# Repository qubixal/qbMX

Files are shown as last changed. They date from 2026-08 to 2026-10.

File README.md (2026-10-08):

# qbMX

> A custom mechanical keyboard built from scratch for [Hack Club Keeb](https://keeb.hackclub.com/) YSWS.

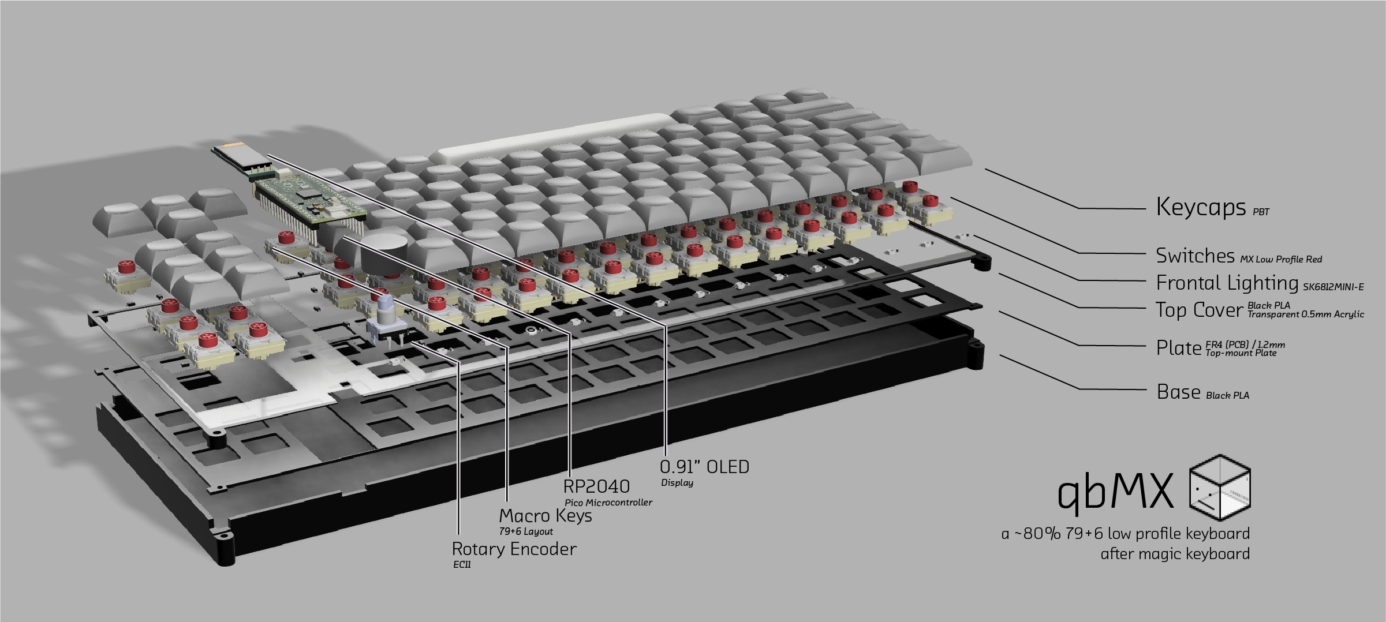
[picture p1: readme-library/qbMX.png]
Full Render


## Overview

**qbMX** is a fully custom mechanical keyboard designed in KiCad and Fusion. It features:

- **85-key (79+6) layout** with a rotary encoder, modelled after Apple's Magic Keyboard.
- **Cherry MX Low-Profile Red** switches, and on-plate stabalisers (instead of on-pcb)
- Uses the **RP2040 microcontroller** (Orpheus Pico)
- A 0.91" **128x32 OLED display**
- 15 mini-LEDs at the top of the keyboard
- Custom PCB, ordered and assembled by me

## Why I Built qbMX

I wanted to learn about and build a keyboard myself, since I'd never done it before.
Designing the matrix and optimising GPIO lanes with functionality was a cool challenge. Oh, and I just wanted a keyboard; and Keeb gave me an excuse to make it.

## What's in This Repo

| Path | Description |
| --- | --- |
| `keeb.kicad_sch` | Schematic |
| `keeb.kicad_pcb` / `keeb.kicad_pro` | KiCad PCB layout & project |
| `pcb/` + `pcb.zip` | Gerbers & drill files (F.Cu, B.Cu, silkscreen, mask, Edge.Cuts) |
| `*.step` | 3D models (board, OLED, rotary encoder, plate) |
| `key-switches.pretty/`, `extra_key.pretty/` | Footprint libraries |
| `readme-library/` | Photos & renders |
| `bom.csv` | Bill of materials |

## Use Guide

After building all physical hardware, download the firmware folder then:

```cmd
export PICO_SDK_PATH=/path/to/pico-sdk

cd firmware && mkdir build && cd build

cmake .. && make
```

hold BOOTSEL on the Pico, plug in the USB and drag qbmx.uf2 to the mass storage device.

OLED Shows 5 pages:
0. Current keyboard layer
1. Custom text/bitmap
2. LED mode + brightness
3. WPM counter with bar graph
4. Host temps (CPU avg, GPU avg, Pico internal temp)

For temperature tracking to work properly,
1. Install pyserial
```cmd
pip3 install pyserial
```
2. Run host script which auto-detects the Pico port
```cmd
python3 firmware/host_temp.py
```

> **Note:** osx-cpu-temp will return 0.0°C on Apple Silicon Macs without SMC entitlements; where the OLED will show N/A in this case. You may instead compile `osx-cpu-temp` from source or use  `sudo powermetrics`.

### Programmable Keys (Column 14, Rows 0-5)
By default they are mapped to F13-F18 (USB HID keycodes 0x68 -> 0x6D), which is recognised by every major OS. It can be remapped in system settings.

Other functions include:
Short press rotary encoder to pause, Long press rotary encoder to toggle between volume and brightness (backlight) mode

## Build Log / Journal

See [`JOURNAL.md`](JOURNAL.md).

## BOM

See [`bom.csv`](bom.csv).

## Acknowledgements

- [Hack Club Keeb](https://keeb.hackclub.com/) for the program
- siderakb/key-switches.pretty and eblaster/marbastlib libraries
- GrabCAD models [switch](https://grabcad.com/library/low-profile-cherry-mx-red-1), [encoder](https://grabcad.com/library/11mm-metal-shaft-rotary-encoders-tht-vertical-w-push-on-switch-1), [OLED](https://grabcad.com/library/0-91-128x32-oled-display-1)
- Github models [keycaps](https://github.com/anhthang/dsa-keycap/)

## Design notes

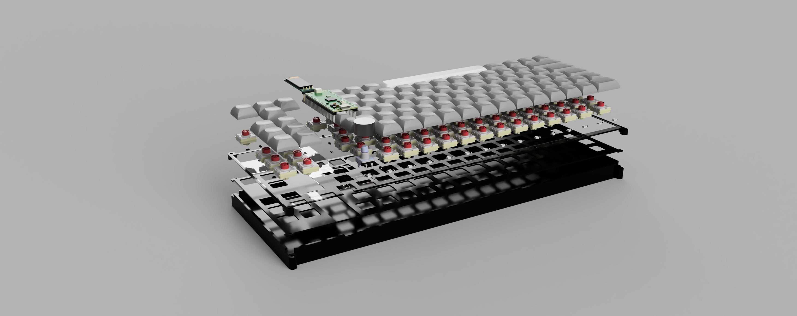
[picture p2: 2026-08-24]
render.PNG

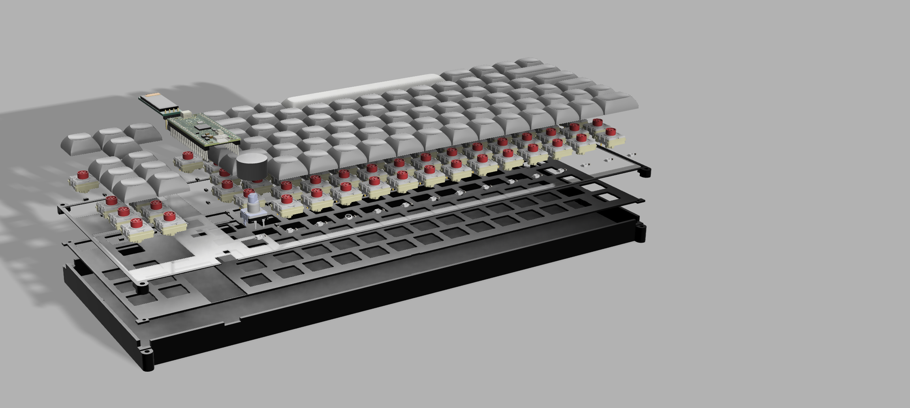
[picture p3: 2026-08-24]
render_clean.png

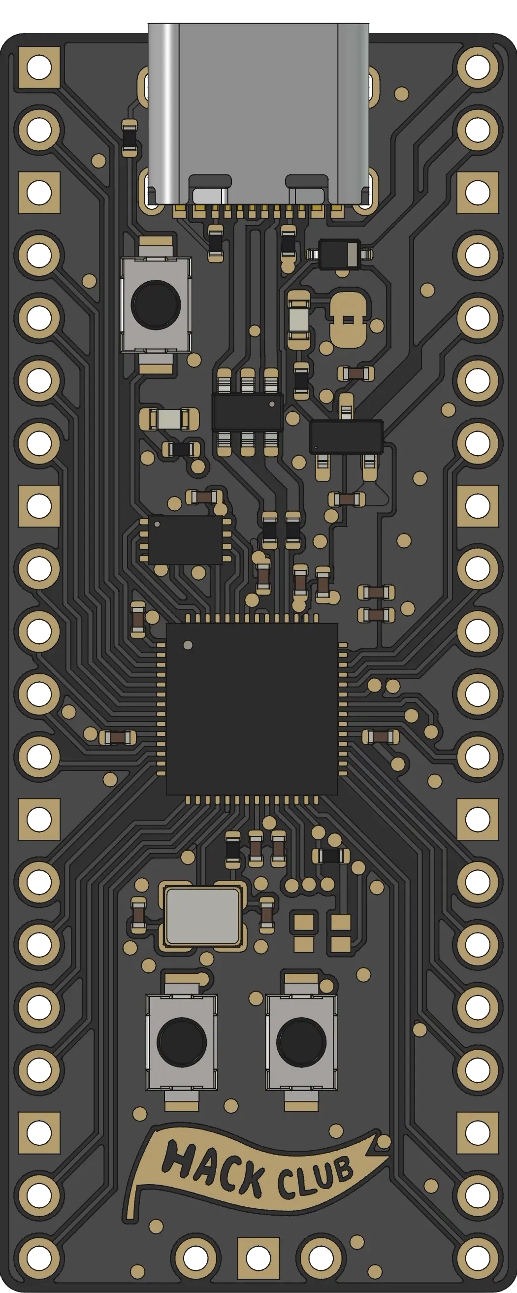
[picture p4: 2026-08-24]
orph-pico.png

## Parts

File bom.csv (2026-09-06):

Designator | Item | Item No/LCSC | Supplier | Variant | Qty | Unit $AUD | Total $AUD | Link
1 | Orpheus Pico |  | Hack Club |  | 1 | ? | ?
2 | Cherry MX Low Profile Red | CHERRY__________________MX Low Profile RGB | Taobao | 100 pack | 1 | 46.04 | 46.04 | https://item.taobao.com/item.htm?id=673935710462
3 | Plate Mount Stab | __Chosfox MX________ ______________ | Taobao | 6.25u*1+2u*2 | 1 | 5.6 | 5.6 | https://item.taobao.com/item.htm?id=921829717536
4 | M3*10 Screw | M2.5M3M4M5M6M8__304___________________ | Taobao | 50 pack | 1 | 1.45 | 1.45 | https://detail.tmall.com/item.htm?id=650868762254
5 | M2*3 Screw | M2_______CM__3.3_0.3_______*2/2.5/3/4/5/10 | Taobao | 100 pack | 1 | 0.62 | 0.62 | https://detail.tmall.com/item.htm?id=610559538489
6 | EC11 Rotary Encoder | EC11________10/15/20/25mm__ ___________ | Taobao | __10mm | 1 | 1.54 | 1.54 | https://item.taobao.com/item.htm?id=586360534043
7 | 1N4148W Diode | C84367 | LCSC |  | 100 | 0.01 | 1 | https://www.lcsc.com/product-detail/C84367.html
8 | 0.91" OLED Screen | 0.91_OLED_____128_32___4_iic__SSD1306 | Taobao | 4PIN 0.91_ _______ | 1 | 1.8 | 1.8 | https://item.taobao.com/item.htm?id=824313570601
9 | 0.1uF 0603 Cap | C14663 | LCSC |  | 50 | 0.02 | 1 | https://www.lcsc.com/product-detail/C14663.html
10 | OPSCO Optoelectronics SK6812MINI-E | C5149201 | LCSC |  | 15 | 0.11 | 1.65 | https://www.lcsc.com/product-detail/C5149201.html
11 | PCB - Keyboard |  | JLCPCB |  | 1 | 32.99 | 32.99
12 | PCB - Plate (FR4) |  | JLCPCB | 1.2mm | 1 | 34.95 | 34.95
13 | PCB Shipping |  | JLCPCB | - | 1 | 21.71 | 21.71
14 | Case (3D print + Acrylic) | - | - | - | - | - | -
15 | Silicone Padding | ______________________________ | Taobao | 15 pack 30*9*1mm | 1 | 1.03 | 1.03
16 | PBT Keycaps | ______ABS\PBT____68\84\98\104\87\100\108__ | Taobao | PBT White Set | 1 | 19.82 | 19.82
17 | Taobao Shipping |  | Taobao | Combined + GST | 1 | 18.61 | 18.61
 |  |  |  |  |  | TOTAL | 189.81
 |  |  |  |  |  | TOTAL (USD) | 136.6632

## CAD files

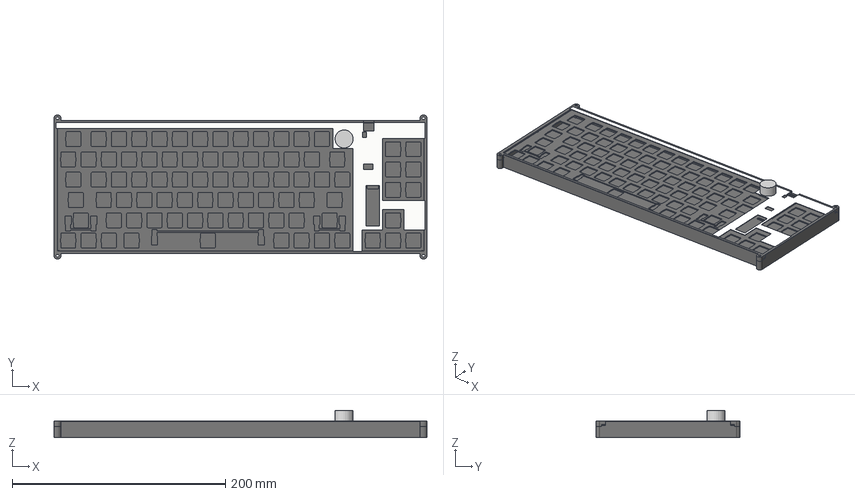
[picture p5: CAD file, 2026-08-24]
case-assembly.step
350.0 x 135.5 x 25.6 mm

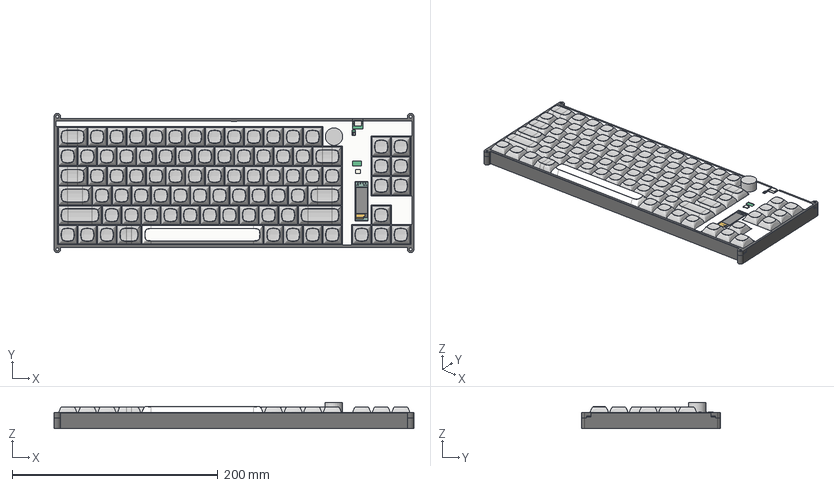
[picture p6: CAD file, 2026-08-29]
prod-3d-models/qbMX-assembly.step
350.0 x 135.5 x 25.6 mm

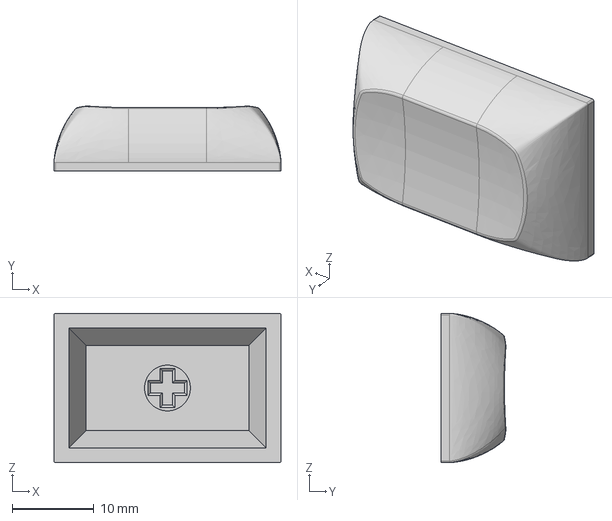
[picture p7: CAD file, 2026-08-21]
dsa-keycap-master/DSA 1.5u.step
27.7 x 7.91 x 18.2 mm

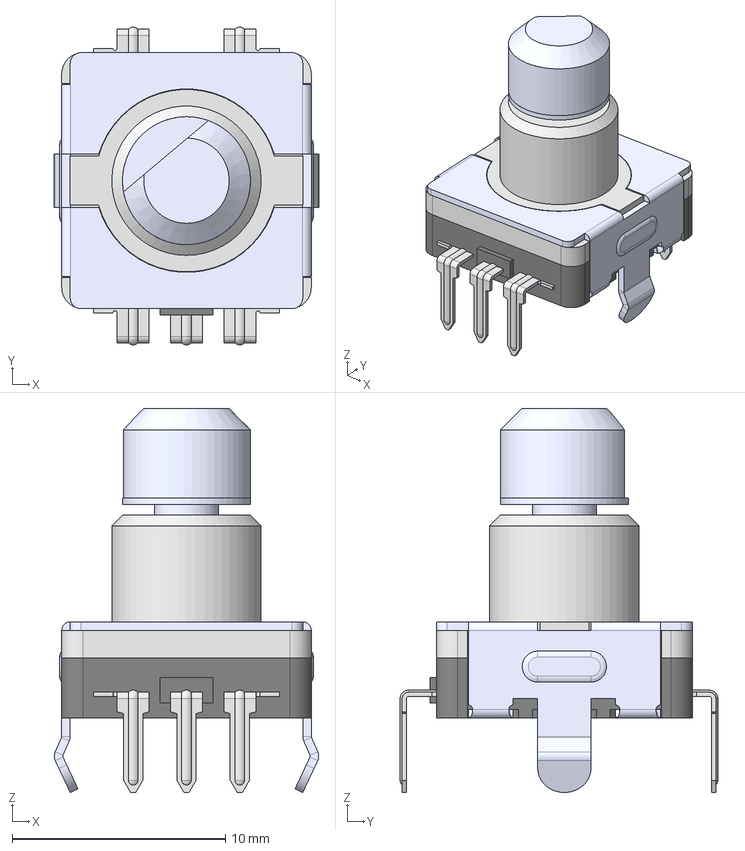
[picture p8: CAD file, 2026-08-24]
EC11-THT-10F-black.step
12.4 x 14.9 x 18.0 mm

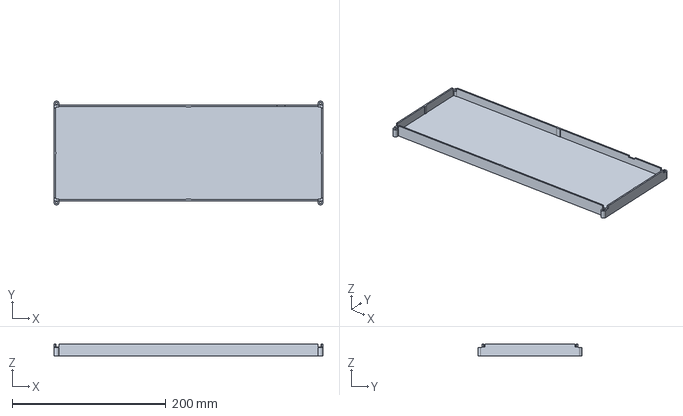
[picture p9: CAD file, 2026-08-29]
prod-3d-models/base.step
350.0 x 135.5 x 15.0 mm

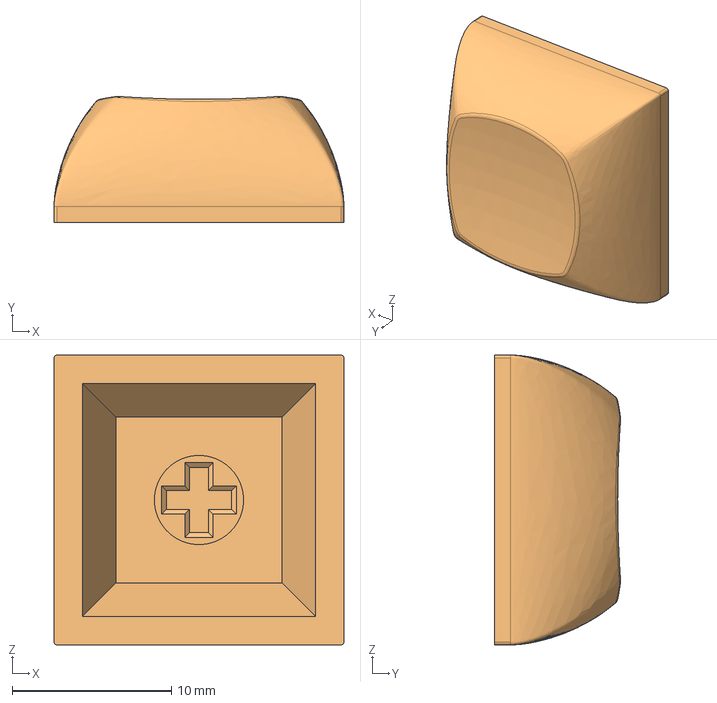
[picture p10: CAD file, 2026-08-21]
dsa-keycap-master/DSA 1u.step
18.2 x 7.91 x 18.2 mm

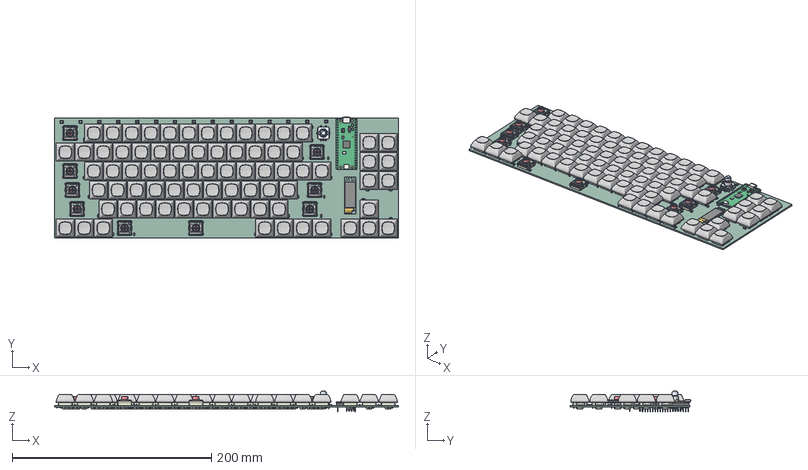
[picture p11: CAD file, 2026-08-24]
pcb.step
345.0 x 121.0 x 20.8 mm
Stem x 85
Top Case x 85
Bottom Case x 85
Spring x 85
MX Mount v1 x 76
D_SOD-123 x 86
128x32-OLED v4
RaspberryPi_Pico_H_Module_KiCad
RaspberryPi_Pico_Header_DIP-40_H2.54mm_KiCad
EC11-Base
EC11-Shaft-F
EC11-Housing-THT
C_0603_1608Metric x 15
Pin1 x 15
Pin2 x 15
Pin3 x 15
Pin4 x 15
keeb_PCB

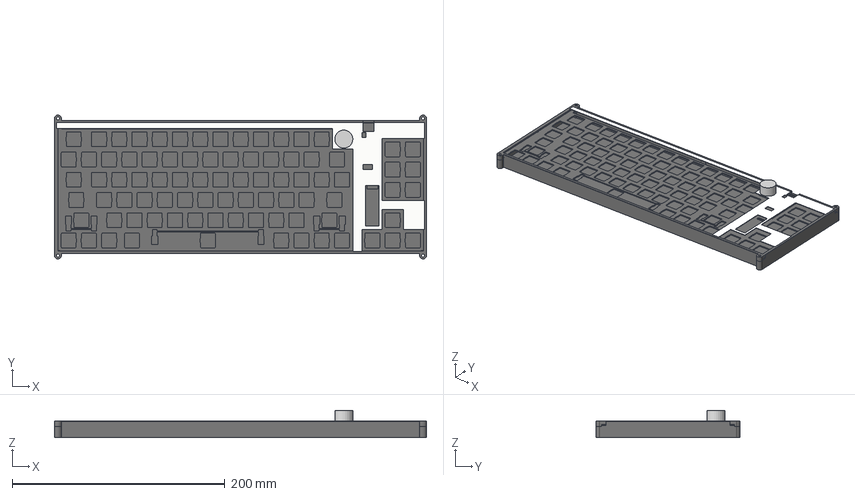
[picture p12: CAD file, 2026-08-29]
prod-3d-models/case.step
350.0 x 135.5 x 25.6 mm

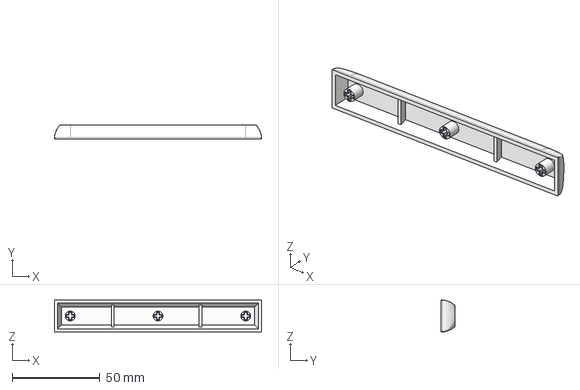
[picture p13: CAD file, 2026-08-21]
dsa-keycap-master/DSA Spacebar 6.25u (50mm spacing).step
118.0 x 8.00 x 18.2 mm

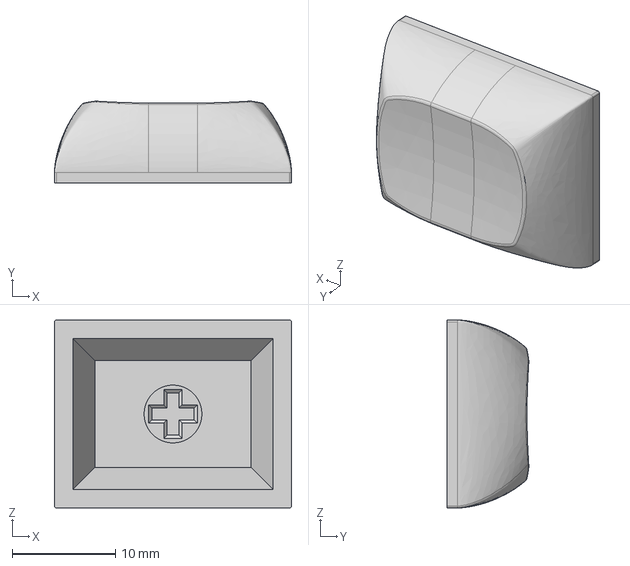
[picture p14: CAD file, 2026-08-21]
dsa-keycap-master/DSA 1.25u.step
22.9 x 7.91 x 18.2 mm

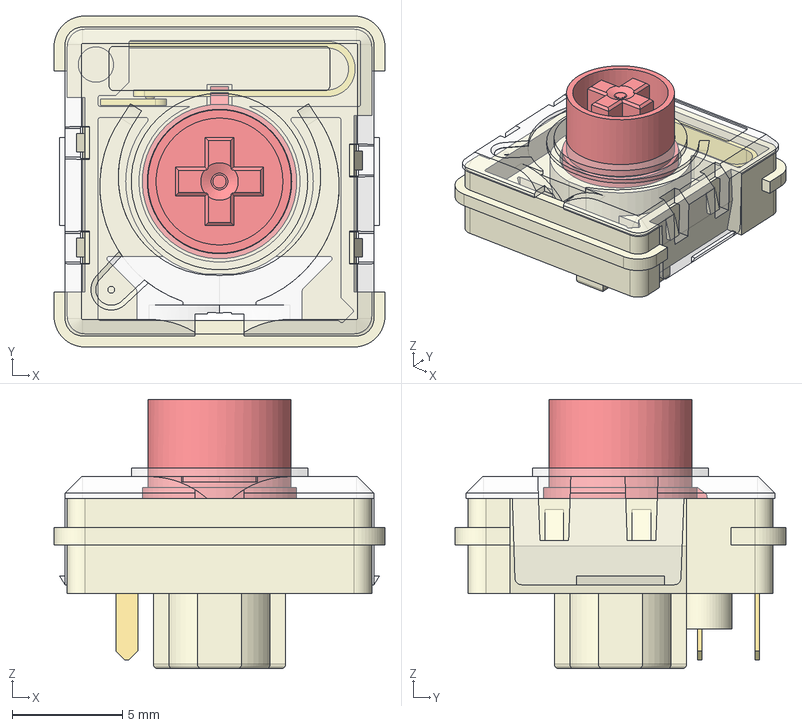
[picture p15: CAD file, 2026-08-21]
lpred.step
15.0 x 15.0 x 12.2 mm
Stem
Top Case
Bottom Case
Spring

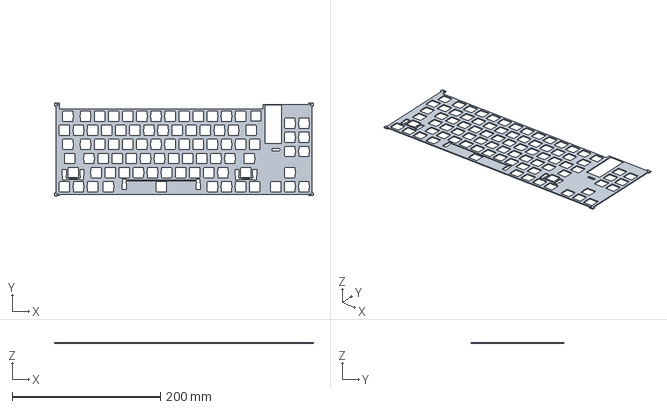
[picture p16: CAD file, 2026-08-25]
prod-3d-models/plate.step
350.0 x 125.0 x 1.20 mm

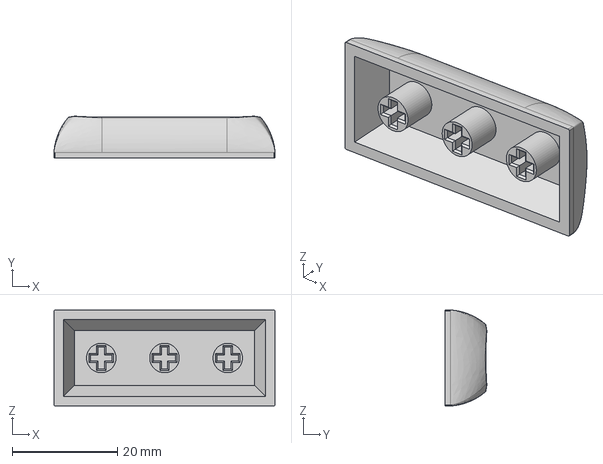
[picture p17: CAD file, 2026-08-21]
dsa-keycap-master/DSA 2.25u.step
42.0 x 7.91 x 18.2 mm

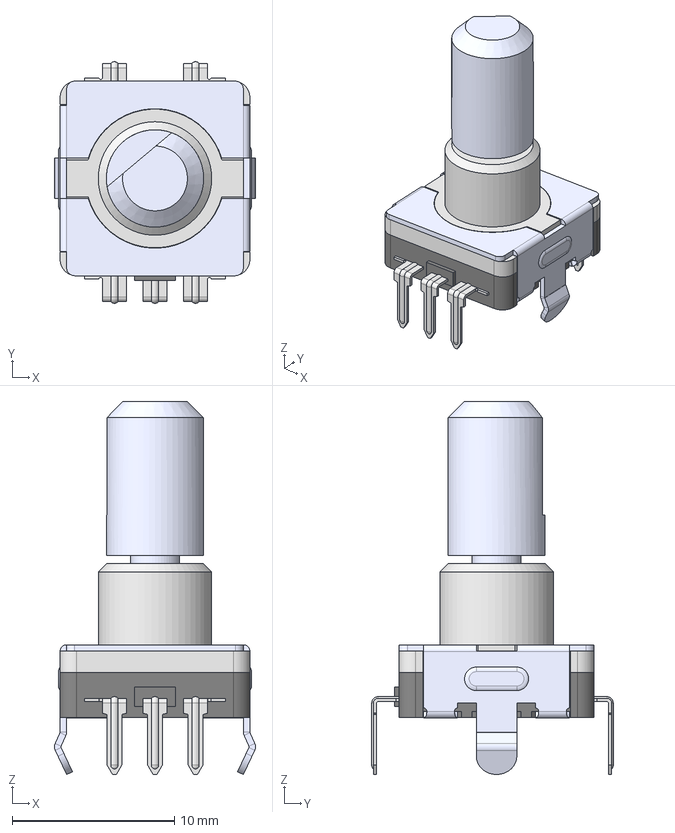
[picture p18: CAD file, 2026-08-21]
EC11-THT-15F-black.step
12.4 x 14.9 x 23.0 mm
Lb5
15F
EC11-Housing-THT

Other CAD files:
prod-3d-models/top-cover.stl
128x32-OLED.STEP
dsa-keycap-master/DSA 1.75u.step
prod-3d-models/knob.stl
prod-3d-models/acrylic-cover.stl
prod-3d-models/base.stl

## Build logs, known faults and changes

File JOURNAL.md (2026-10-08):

---
title: "qbMX"
author: "qubixal"
description: "A custom 85-key mechanical keyboard designed from scratch in KiCad and Fusion, with an RP2040, OLED display, rotary encoder and per-key LEDs."
created_at: "2026-08-20"
---

*note, the KiCad project was not git initialised, and so does not show up under hackatime as a distinct project. The hours are accurate estimates based on daily overviews.

# August 21: Planning & schematic

I followed the guide and started planning. Functionalities:
RP2040 microcontroller (), 0.91" OLED screen (2 GPIO), Rotary Encoder (2 GPIO), Keys (21 GPIO, 6 rows 15 columns), "Backlight" (1GPIO) total 26GPIO.

Originally, i designed this for standard size MX switches and did not understand the difference, keyboard sizes (i.e. 60%, 75%, 80%, etc) or keycap u sizes.
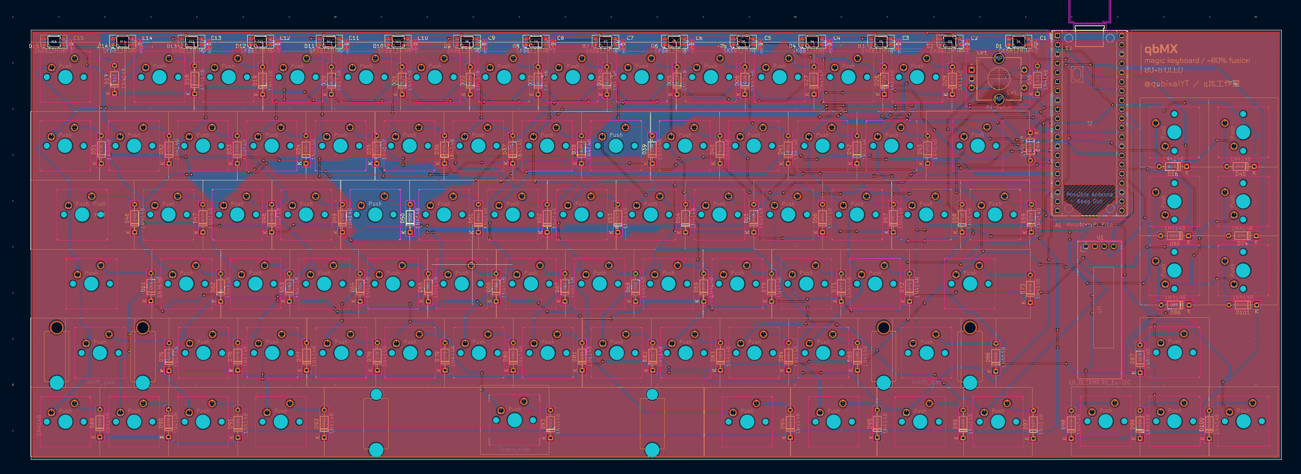
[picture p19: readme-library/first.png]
1st


I handplaced each key which resulted in this taking ages. At this time, I just autorouted to save some time.

**Total time spent: 5 hours**

# August 21: PCB layout

Hand-routed the matrix. When I applied the 3D models, I noticed something was off and reconfigured everything.
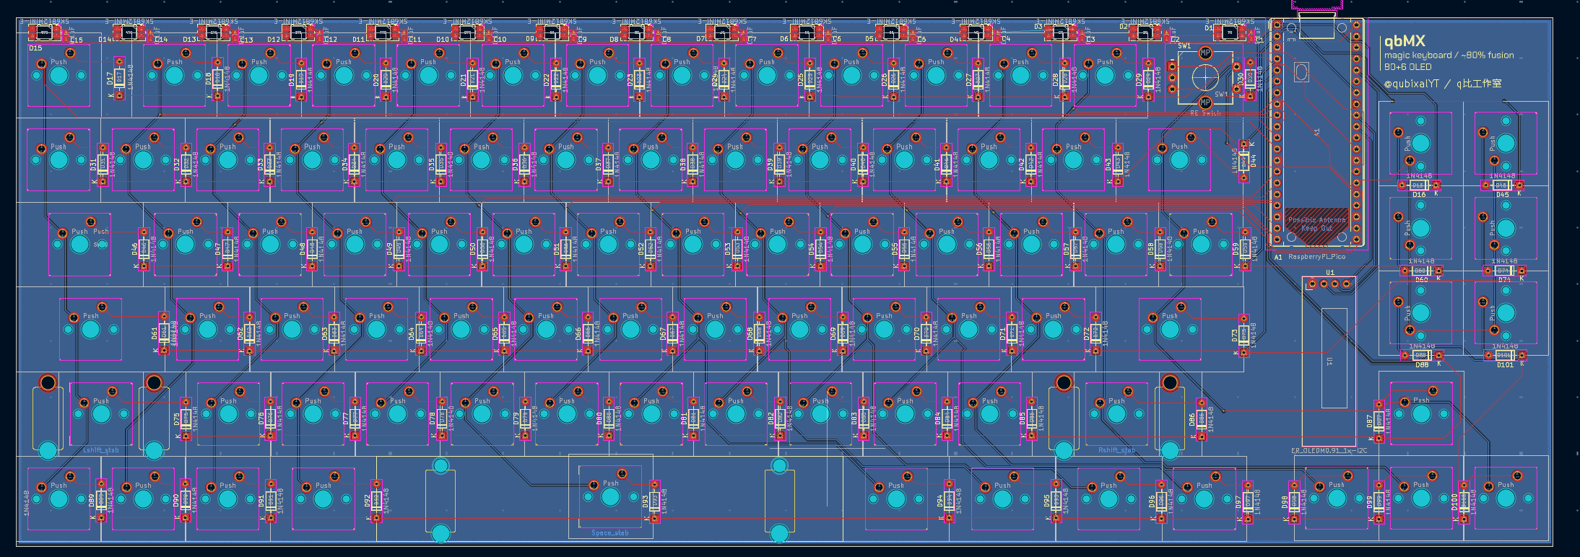
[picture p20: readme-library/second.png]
2nd


**Total time spent: 2 hours**

# August 22: Redesign

Refactored entire keyboard from scratch after several issues with geographical annotation messing up the keys. Other key changes that happened were:
MX switches -> MX Low Profile Red switches,
On-PCB Stabalisers -> On-Plate Stabalisers (due to lack of footprints available)
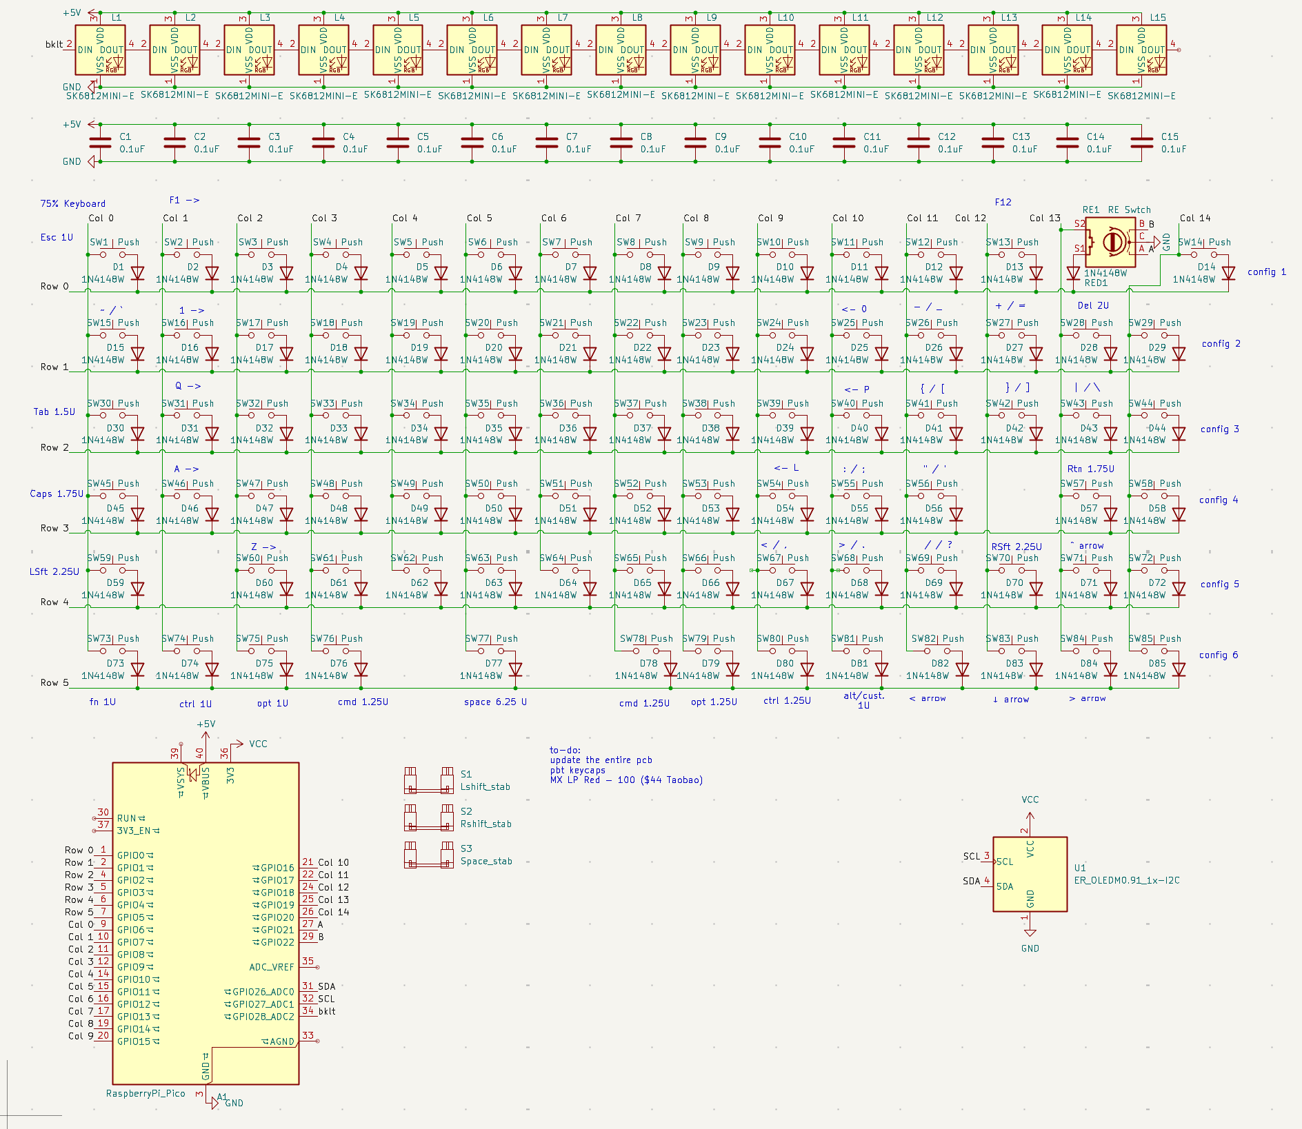
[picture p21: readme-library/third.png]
3rd


Marbastlib was so useless and had nothing, so I had to refactor what I had anyways. Switched to a mix of Marbastlib and siderakb/key-switches.pretty.
To save time placing components, i installed kbplacer. However, i had to retweak every reference number because my LEDs conflicted with diodes, and rotary encoder was counted as a switch. Doing this wouldn't have been a problem if my keyboard wasn't already laid out.

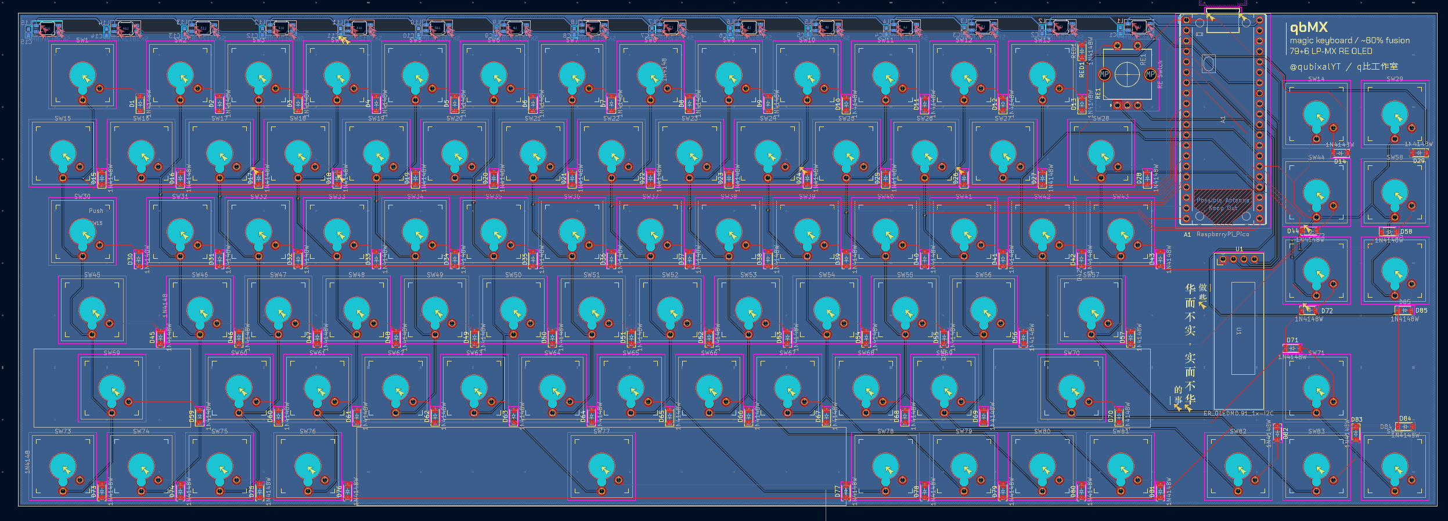
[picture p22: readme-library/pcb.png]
pcb


I also fetched the 3D models for everything and exported to fusion which took a long time yet again, as I had to find a new rotary encoder with an appropriate height.

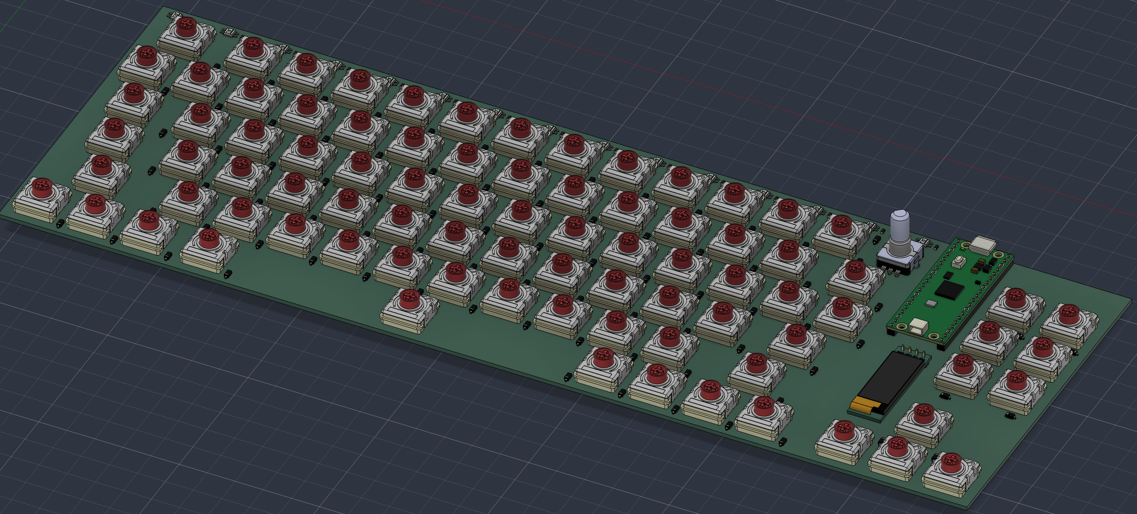
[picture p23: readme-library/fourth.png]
4th


**Total time spent: 6 hours**

# August 24: Outer case design

Added keycaps to the model.
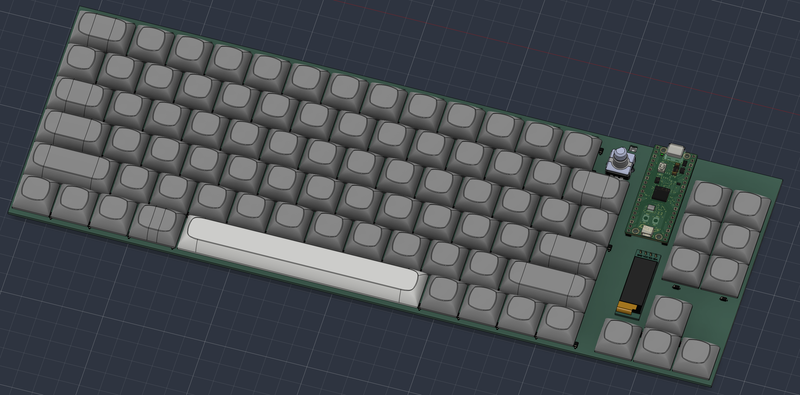
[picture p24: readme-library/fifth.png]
5th


Also, modified the bottom so that I could stick in silicone stoppers.
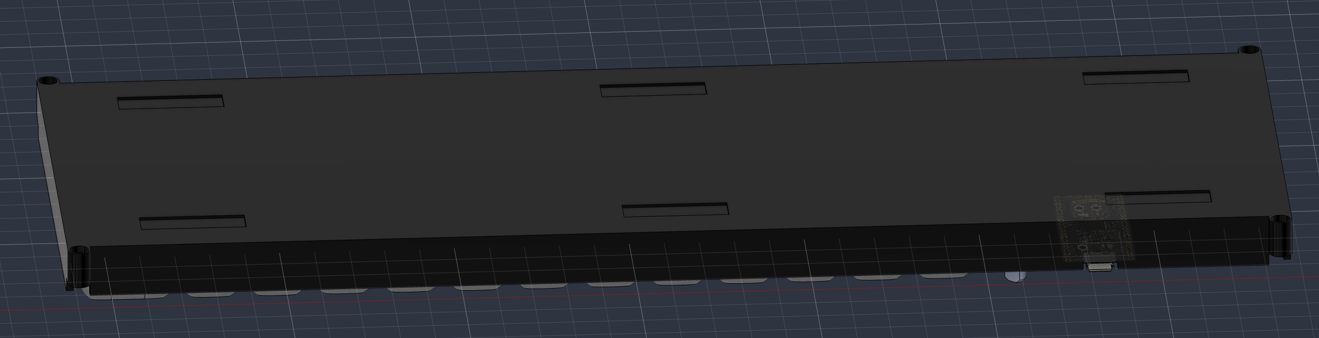
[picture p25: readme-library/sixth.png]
6th


Exported STEP files are available in /prod-3d-models.

So how the heck did creating a rectangle box of doom and despair take 8 hours?
I think it can be explained in one screenshot:
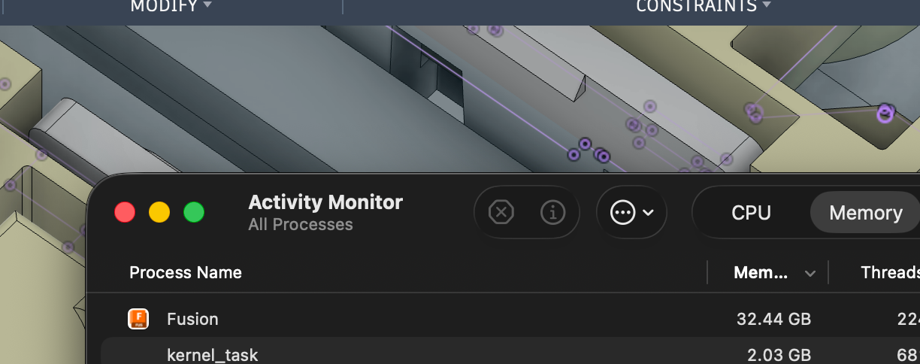
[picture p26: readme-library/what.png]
stupid fusion


In case you're still clueless, that's fusion taking up 32GB of ram. Apparently having 85 switches and a few more bits ad pieces kills your computer.

I'm still quite happy with the end result. The overall hierarchy is:
<br>------- Top cover (+ acrylic sheet), 0.5mm
<br>keycaps + microcontroller
<br>------- Plate (FR4, in PCB form), 1.2mm
<br>switches and PCB
<br>------- Bottom Case
The overall design is a Top mount keyboard design.
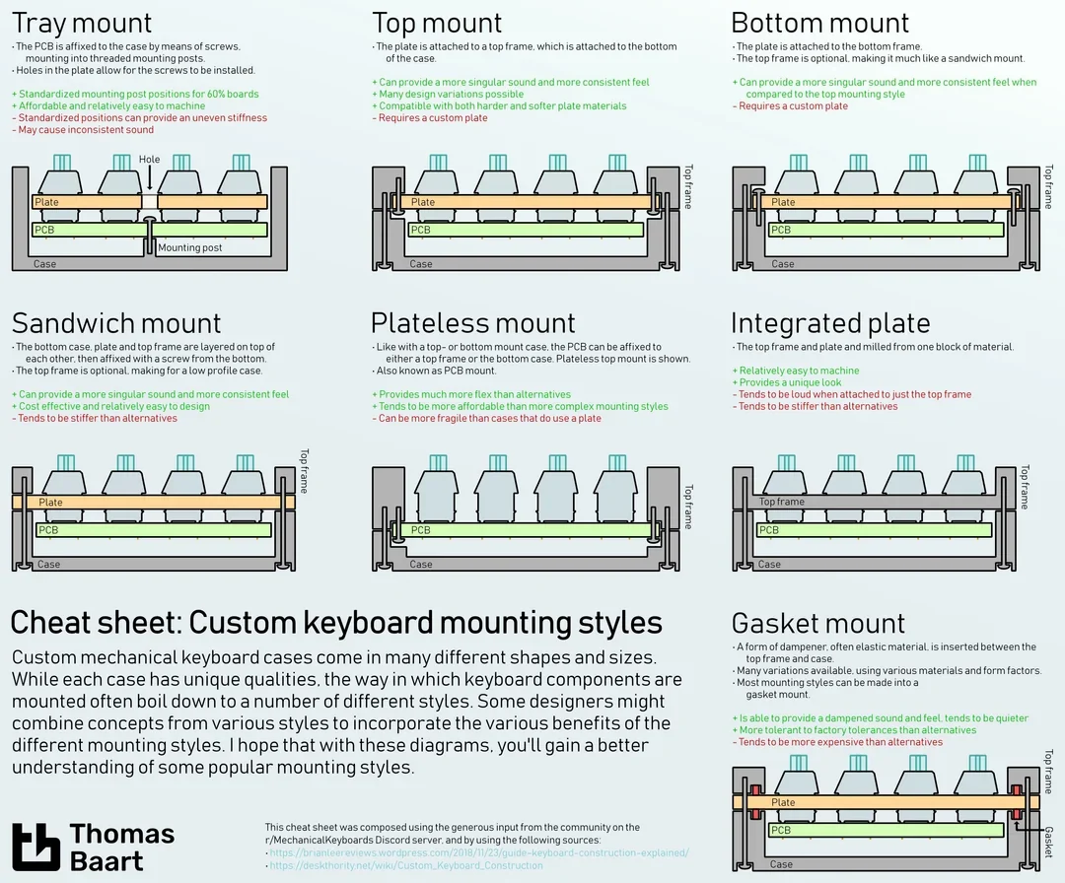
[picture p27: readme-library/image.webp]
keyboard type


**Total time spent: 8 hours**

# August 25: Ordering & assembly

BOM is almost finalised.
Total expected cost of project is: ~$136 usd (excluding orpheus pico).
The final render is seen below:
render

**Total time spent: 1 hour**

# August 28: Firmware

Wrote bare-metal Pico SDK firmware (in C) for the RP2040 microcontroller. Each file is broken down below:
- **matrix.c**: scans the 6x15 keyboard with 5ms per-key debouncing
- **usb_descriptors.c**: device identification + HID report, USB VID:PID 0xCafe:0x4005
- **oled.c**: SSD1306 128x32 OLED driver over I2C1 with 5 toggleable pages (listed on README)
- **leds.c**: 15 SK6812MINI-E LED chain via PIO, with a startup rainbow wave animation + warm white / RGB cycle modes
- **encoder.c**: rotary encoder, quadrature decoding -> volume up/down
- **main.c**: 1ms polling rate that controls everything, calculates WPM and manages RP2040 internal temp sensor.

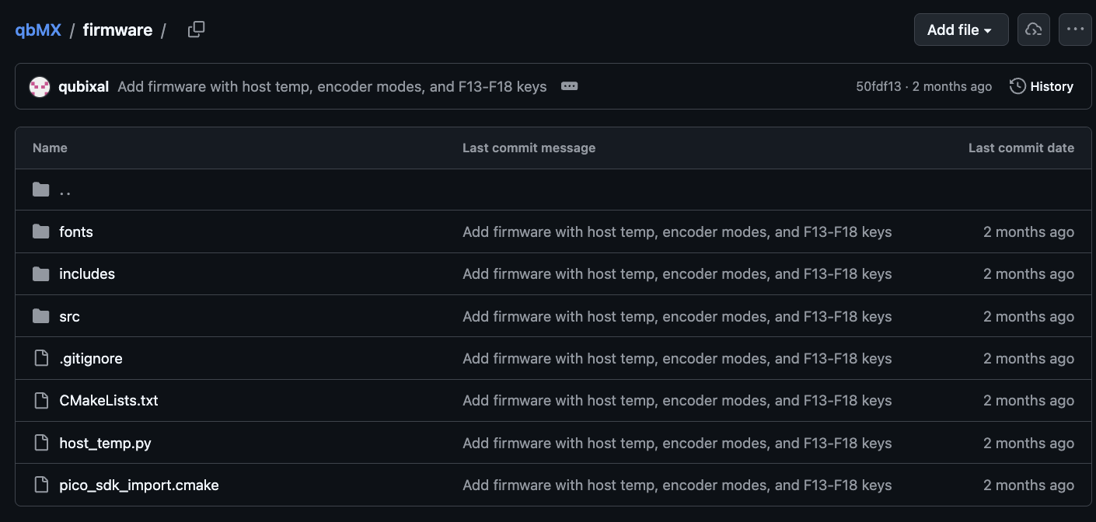
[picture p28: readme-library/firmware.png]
firmware


> NOTE: AI WAS USED to dramatically speed up the matrix and fonts; saving me a lot of work here.

USB CDC serial interface was added to receive Mac CPU/GPU temperatures, using the protocol `T:<cpu_avg>:<gpu_avg>\n` over USB serial at 115200 baud.
Host-side Python script (`host_temp.py`) reads Mac temps via `osx-cpu-temp` and sends to Pico, and it is then displayed on a page on the OLED Screen.

**Total time spent: 3 hours**

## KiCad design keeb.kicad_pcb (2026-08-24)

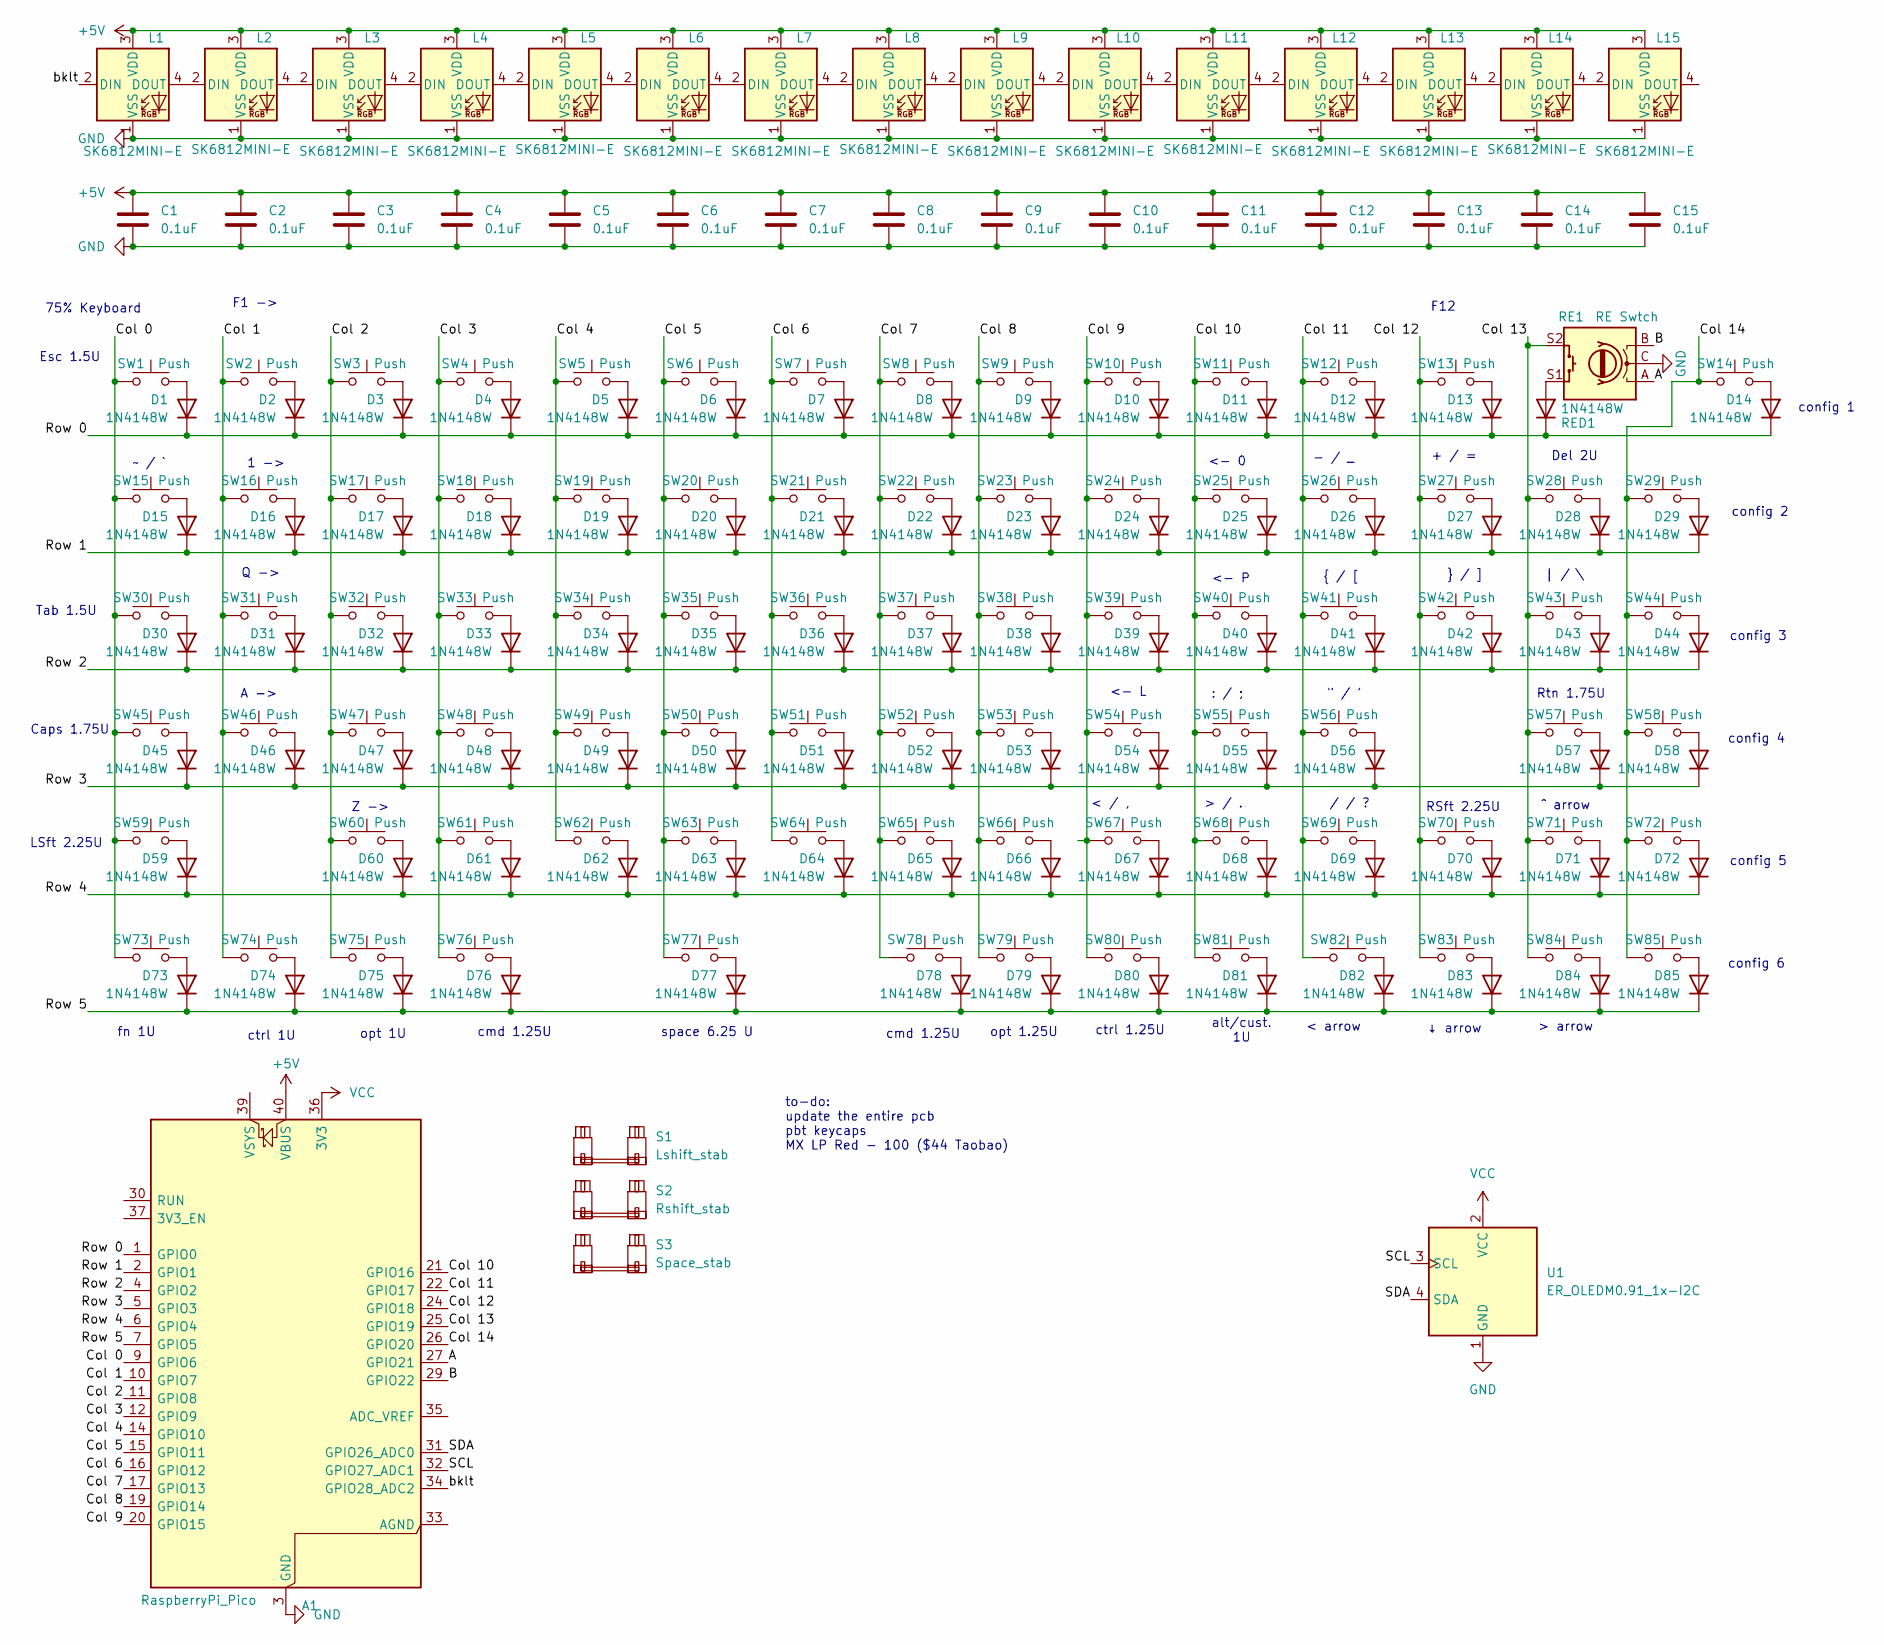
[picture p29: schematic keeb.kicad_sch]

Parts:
A1: RaspberryPi_Pico; RaspberryPi_Pico_Common_THT
C1, C2, C3, C4, C5, C6, C7, C8, C9, C10, C11, C12, C13, C14, C15: 0.1uF; C_0603_1608Metric
D1, D2, D3, D4, D5, D6, D7, D8, D9, D10, D11, D12, D13, D14, D15, D16, D17, D18, D19, D20, D21, D22, D23, D24, D25, D26, D27, D28, D29, D30, D31, D32, D33, D34, D35, D36, D37, D38, D39, D40, D41, D42, D43, D44, D45, D46, D47, D48, D49, D50, D51, D52, D53, D54, D55, D56, D57, D58, D59, D60, D61, D62, D63, D64, D65, D66, D67, D68, D69, D70, D71, D72, D73, D74, D75, D76, D77, D78, D79, D80, D81, D82, D83, D84, D85: 1N4148W; D_SOD-123
L1, L2, L3, L4, L5, L6, L7, L8, L9, L10, L11, L12, L13, L14, L15: SK6812MINI-E; LED_SK6812MINI-E_3.2x2.8mm_P1.5mm_ReverseMount
RE1: RE Swtch; RotaryEncoder_Alps_EC11E-Switch_Vertical_H20mm_CircularMoun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
RED1: 1N4148W; D_SOD-123
S1: Lshift_stab; STAB_MX_P_2u
S2: Rshift_stab; STAB_MX_P_2u
S3: Space_stab; STAB_MX_6.25u
SW1, SW2, SW3, SW4, SW5, SW6, SW7, SW8, SW9, SW10, SW11, SW12, SW13, SW14, SW15, SW16, SW17, SW18, SW19, SW20, SW21, SW22, SW23, SW24, SW25, SW26, SW27, SW28, SW29, SW30, SW31, SW32, SW33, SW34, SW35, SW36, SW37, SW38, SW39, SW40, SW41, SW42, SW43, SW44, SW45, SW46, SW47, SW48, SW49, SW50, SW51, SW52, SW53, SW54, SW55, SW56, SW57, SW58, SW59, SW60, SW61, SW62, SW63, SW64, SW65, SW66, SW67, SW68, SW69, SW70, SW71, SW72, SW73, SW74, SW75, SW76, SW77, SW78, SW79, SW80, SW81, SW82, SW83, SW84, SW85: Push; SW_MX_LowProfile_THT
U1: ER_OLEDM0.91_1x-I2C

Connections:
+5V: A1.40 (VBUS), C1.1, C2.1, C3.1, C4.1, C5.1, C6.1, C7.1, C8.1, C9.1, C10.1, C11.1, C12.1, C13.1, C14.1, C15.1, L1.3 (VDD), L2.3 (VDD), L3.3 (VDD), L4.3 (VDD), L5.3 (VDD), L6.3 (VDD), L7.3 (VDD), L8.3 (VDD), L9.3 (VDD), L10.3 (VDD), L11.3 (VDD), L12.3 (VDD), L13.3 (VDD), L14.3 (VDD), L15.3 (VDD)
/A: A1.27 (GPIO21), RE1.A
/B: A1.29 (GPIO22), RE1.B
/Col 0: A1.9 (GPIO6), SW1.1, SW15.1, SW30.1, SW45.1, SW59.1, SW73.1
/Col 1: A1.10 (GPIO7), SW2.1, SW16.1, SW31.1, SW46.1, SW74.1
/Col 2: A1.11 (GPIO8), SW3.1, SW17.1, SW32.1, SW47.1, SW60.1, SW75.1
/Col 3: A1.12 (GPIO9), SW4.1, SW18.1, SW33.1, SW48.1, SW61.1, SW76.1
/Col 4: A1.14 (GPIO10), SW5.1, SW19.1, SW34.1, SW49.1, SW62.1
/Col 5: A1.15 (GPIO11), SW6.1, SW20.1, SW35.1, SW50.1, SW63.1, SW77.1
/Col 6: A1.16 (GPIO12), SW7.1, SW21.1, SW36.1, SW51.1, SW64.1
/Col 7: A1.17 (GPIO13), SW8.1, SW22.1, SW37.1, SW52.1, SW65.1, SW78.1
/Col 8: A1.19 (GPIO14), SW9.1, SW23.1, SW38.1, SW53.1, SW66.1, SW79.1
/Col 9: A1.20 (GPIO15), SW10.1, SW24.1, SW39.1, SW54.1, SW67.1, SW80.1
/Col 10: A1.21 (GPIO16), SW11.1, SW25.1, SW40.1, SW55.1, SW68.1, SW81.1
/Col 11: A1.22 (GPIO17), SW12.1, SW26.1, SW41.1, SW56.1, SW69.1, SW82.1
/Col 12: A1.24 (GPIO18), SW13.1, SW27.1, SW42.1, SW70.1, SW83.1
/Col 13: A1.25 (GPIO19), RE1.S2, SW28.1, SW43.1, SW57.1, SW71.1, SW84.1
/Col 14: A1.26 (GPIO20), SW14.1, SW29.1, SW44.1, SW58.1, SW72.1, SW85.1
/Row 0: A1.1 (GPIO0), D1.1 (K), D2.1 (K), D3.1 (K), D4.1 (K), D5.1 (K), D6.1 (K), D7.1 (K), D8.1 (K), D9.1 (K), D10.1 (K), D11.1 (K), D12.1 (K), D13.1 (K), D14.1 (K), RED1.1 (K)
/Row 1: A1.2 (GPIO1), D15.1 (K), D16.1 (K), D17.1 (K), D18.1 (K), D19.1 (K), D20.1 (K), D21.1 (K), D22.1 (K), D23.1 (K), D24.1 (K), D25.1 (K), D26.1 (K), D27.1 (K), D28.1 (K), D29.1 (K)
/Row 2: A1.4 (GPIO2), D30.1 (K), D31.1 (K), D32.1 (K), D33.1 (K), D34.1 (K), D35.1 (K), D36.1 (K), D37.1 (K), D38.1 (K), D39.1 (K), D40.1 (K), D41.1 (K), D42.1 (K), D43.1 (K), D44.1 (K)
/Row 3: A1.5 (GPIO3), D45.1 (K), D46.1 (K), D47.1 (K), D48.1 (K), D49.1 (K), D50.1 (K), D51.1 (K), D52.1 (K), D53.1 (K), D54.1 (K), D55.1 (K), D56.1 (K), D57.1 (K), D58.1 (K)
/Row 4: A1.6 (GPIO4), D59.1 (K), D60.1 (K), D61.1 (K), D62.1 (K), D63.1 (K), D64.1 (K), D65.1 (K), D66.1 (K), D67.1 (K), D68.1 (K), D69.1 (K), D70.1 (K), D71.1 (K), D72.1 (K)
/Row 5: A1.7 (GPIO5), D73.1 (K), D74.1 (K), D75.1 (K), D76.1 (K), D77.1 (K), D78.1 (K), D79.1 (K), D80.1 (K), D81.1 (K), D82.1 (K), D83.1 (K), D84.1 (K), D85.1 (K)
/SCL: A1.32 (GPIO27_ADC1), U1.3 (SCL)
/SDA: A1.31 (GPIO26_ADC0), U1.4 (SDA)
/bklt: A1.34 (GPIO28_ADC2), L1.2 (DIN)
GND: A1.3 (GND), A1.8 (GND), A1.13 (GND), A1.18 (GND), A1.23 (GND), A1.28 (GND), A1.38 (GND), C1.2, C2.2, C3.2, C4.2, C5.2, C6.2, C7.2, C8.2, C9.2, C10.2, C11.2, C12.2, C13.2, C14.2, C15.2, L1.1 (VSS), L2.1 (VSS), L3.1 (VSS), L4.1 (VSS), L5.1 (VSS), L6.1 (VSS), L7.1 (VSS), L8.1 (VSS), L9.1 (VSS), L10.1 (VSS), L11.1 (VSS), L12.1 (VSS), L13.1 (VSS), L14.1 (VSS), L15.1 (VSS), RE1.C, U1.1 (GND)
unnamed: D1.2 (A), SW1.2
unnamed: D2.2 (A), SW2.2
unnamed: D3.2 (A), SW3.2
unnamed: D4.2 (A), SW4.2
unnamed: D5.2 (A), SW5.2
unnamed: D6.2 (A), SW6.2
unnamed: D7.2 (A), SW7.2
unnamed: D8.2 (A), SW8.2
unnamed: D9.2 (A), SW9.2
unnamed: D10.2 (A), SW10.2
unnamed: D11.2 (A), SW11.2
unnamed: D12.2 (A), SW12.2
unnamed: D13.2 (A), SW13.2
unnamed: D14.2 (A), SW14.2
unnamed: D15.2 (A), SW15.2
unnamed: D16.2 (A), SW16.2
unnamed: D17.2 (A), SW17.2
unnamed: D18.2 (A), SW18.2
unnamed: D19.2 (A), SW19.2
unnamed: D20.2 (A), SW20.2
unnamed: D21.2 (A), SW21.2
unnamed: D22.2 (A), SW22.2
unnamed: D23.2 (A), SW23.2
unnamed: D24.2 (A), SW24.2
unnamed: D25.2 (A), SW25.2
unnamed: D26.2 (A), SW26.2
unnamed: D27.2 (A), SW27.2
unnamed: D28.2 (A), SW28.2
unnamed: D29.2 (A), SW29.2
unnamed: D30.2 (A), SW30.2
unnamed: D31.2 (A), SW31.2
unnamed: D32.2 (A), SW32.2
unnamed: D33.2 (A), SW33.2
unnamed: D34.2 (A), SW34.2
unnamed: D35.2 (A), SW35.2
unnamed: D36.2 (A), SW36.2
unnamed: D37.2 (A), SW37.2
unnamed: D38.2 (A), SW38.2
unnamed: D39.2 (A), SW39.2
unnamed: D40.2 (A), SW40.2
unnamed: D41.2 (A), SW41.2
unnamed: D42.2 (A), SW42.2
unnamed: D43.2 (A), SW43.2
unnamed: D44.2 (A), SW44.2
unnamed: D45.2 (A), SW45.2
unnamed: D46.2 (A), SW46.2
unnamed: D47.2 (A), SW47.2
unnamed: D48.2 (A), SW48.2
unnamed: D49.2 (A), SW49.2
unnamed: D50.2 (A), SW50.2
unnamed: D51.2 (A), SW51.2
unnamed: D52.2 (A), SW52.2
unnamed: D53.2 (A), SW53.2
unnamed: D54.2 (A), SW54.2
unnamed: D55.2 (A), SW55.2
unnamed: D56.2 (A), SW56.2
unnamed: D57.2 (A), SW57.2
unnamed: D58.2 (A), SW58.2
unnamed: D59.2 (A), SW59.2
unnamed: D60.2 (A), SW60.2
unnamed: D61.2 (A), SW61.2
unnamed: D62.2 (A), SW62.2
unnamed: D63.2 (A), SW63.2
unnamed: D64.2 (A), SW64.2
unnamed: D65.2 (A), SW65.2
unnamed: D66.2 (A), SW66.2
unnamed: D67.2 (A), SW67.2
unnamed: D68.2 (A), SW68.2
unnamed: D69.2 (A), SW69.2
unnamed: D70.2 (A), SW70.2
unnamed: D71.2 (A), SW71.2
unnamed: D72.2 (A), SW72.2
unnamed: D73.2 (A), SW73.2
unnamed: D74.2 (A), SW74.2
unnamed: D75.2 (A), SW75.2
unnamed: D76.2 (A), SW76.2
unnamed: D77.2 (A), SW77.2
unnamed: D78.2 (A), SW78.2
unnamed: D79.2 (A), SW79.2
unnamed: D80.2 (A), SW80.2
unnamed: D81.2 (A), SW81.2
unnamed: D82.2 (A), SW82.2
unnamed: D83.2 (A), SW83.2
unnamed: D84.2 (A), SW84.2
unnamed: D85.2 (A), SW85.2
unnamed: L1.4 (DOUT), L2.2 (DIN)
unnamed: L2.4 (DOUT), L3.2 (DIN)
unnamed: L3.4 (DOUT), L4.2 (DIN)
unnamed: L4.4 (DOUT), L5.2 (DIN)
unnamed: L5.4 (DOUT), L6.2 (DIN)
unnamed: L6.4 (DOUT), L7.2 (DIN)
unnamed: L7.4 (DOUT), L8.2 (DIN)
unnamed: L8.4 (DOUT), L9.2 (DIN)
unnamed: L9.4 (DOUT), L10.2 (DIN)
unnamed: L10.4 (DOUT), L11.2 (DIN)
unnamed: L11.4 (DOUT), L12.2 (DIN)
unnamed: L12.4 (DOUT), L13.2 (DIN)
unnamed: L13.4 (DOUT), L14.2 (DIN)
unnamed: L14.4 (DOUT), L15.2 (DIN)
unnamed: RE1.S1, RED1.2 (A)
VCC: A1.36 (3V3), U1.2 (VCC)

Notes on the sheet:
config 1
F12
: / ;
config 5
> / .
Caps 1.75U
opt 1.25U
F1 ->
} / ]
config 6
Q ->
75% Keyboard
< / ,
fn 1U
cmd 1.25U
Tab 1.5U
↓ arrow
| / \
- / _
^ arrow
> arrow
Del 2U
LSft 2.25U
space 6.25 U
ctrl 1.25U
Rtn 1.75U
config 2
~ / `
<- 0
{ / [
config 4
1 ->
<- P
<- L
config 3
opt 1U
" / '
Esc 1.5U
A ->
to-do: update the entire pcb pbt keycaps MX LP Red - 100 ($44 Taobao)

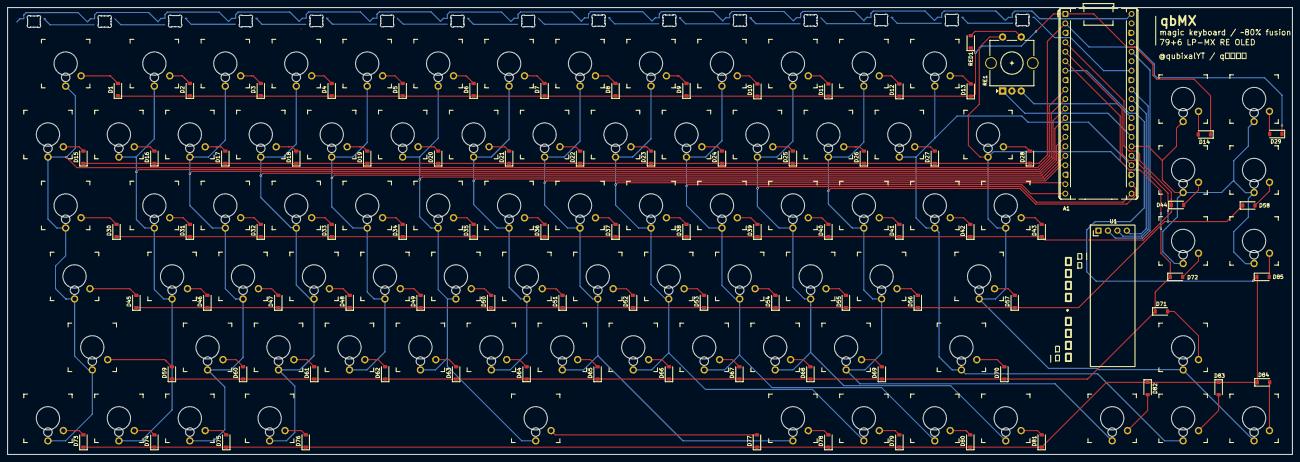
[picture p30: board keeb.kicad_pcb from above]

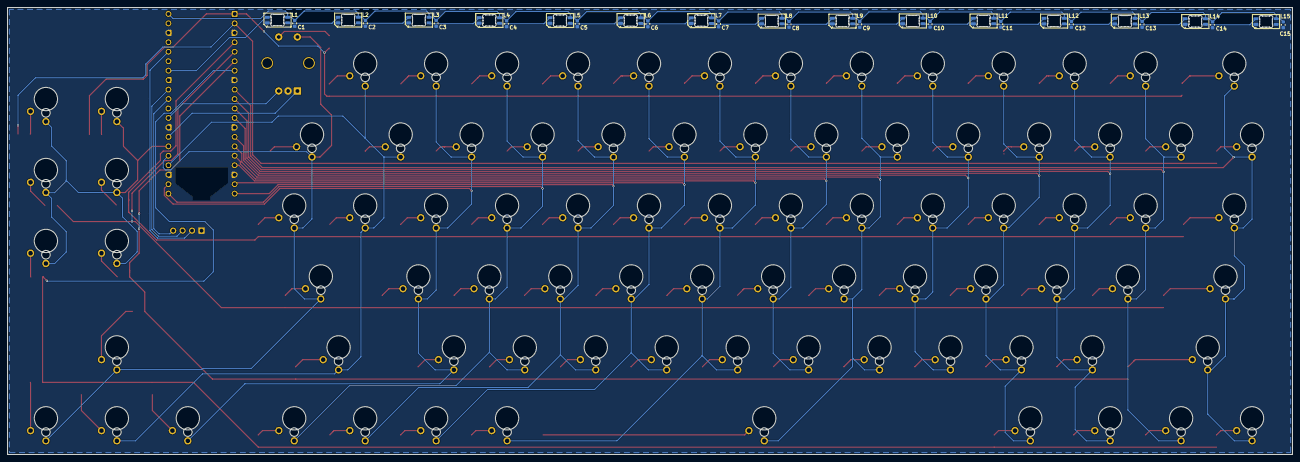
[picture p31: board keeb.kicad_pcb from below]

Board: 2 copper layers, 345.0 x 120.0 mm, 204 parts (30 on the bottom side), 129 nets.

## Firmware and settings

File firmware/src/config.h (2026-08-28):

#ifndef CONFIG_H
#define CONFIG_H

#include "pico/stdlib.h"

// ── Matrix pins ──────────────────────────────────────────────
#define MATRIX_ROWS     6
#define MATRIX_COLS     15

#define ROW_0           0
#define ROW_1           1
#define ROW_2           2
#define ROW_3           3
#define ROW_4           4
#define ROW_5           5

#define COL_0           6
#define COL_1           7
#define COL_2           8
#define COL_3           9
#define COL_4           10
#define COL_5           11
#define COL_6           12
#define COL_7           13
#define COL_8           14
#define COL_9           15
#define COL_10          16
#define COL_11          17
#define COL_12          18
#define COL_13          19
#define COL_14          20

// ── Encoder pins ─────────────────────────────────────────────
#define ENCODER_A       21
#define ENCODER_B       22
#define ENC_A           ENCODER_A
#define ENC_B           ENCODER_B

// ── OLED I2C ─────────────────────────────────────────────────
#define OLED_I2C        i2c1
#define OLED_I2C_INST   i2c1
#define OLED_SDA        26
#define OLED_SCL        27
#define OLED_ADDR       0x3C
#define OLED_I2C_ADDR   0x3C
#define OLED_I2C_FREQ   400000
#define OLED_WIDTH      128
#define OLED_HEIGHT     32

// ── SK6812 LEDs ──────────────────────────────────────────────
#define LED_DATA_PIN    28
#define LED_COUNT       15
#define LED_PIO         pio0
#define LED_SM          0

// ── Timing ───────────────────────────────────────────────────
#define SCAN_INTERVAL_US    1000    // 1ms for matrix scan
#define DEBOUNCE_MS         5       // 5ms debounce
#define OLED_INTERVAL_MS    100     // 10Hz
#define LED_UPDATE_MS       16      // 60fps LED
#define WPM_WINDOW_MS       5000    // 5-second WPM window

// ── USB ──────────────────────────────────────────────────────
#define USB_VID          0xCafe
#define USB_PID          0x4005
#define USB_MANUF        "qbMX"
#define USB_MANUFACTURER "qbMX"
#define USB_PRODUCT      "qbMX Keyboard"

// ── Defaults ─────────────────────────────────────────────────
#define DEFAULT_BRIGHTNESS    128
#define DEFAULT_LED_BRIGHTNESS 128
#define DEFAULT_LED_MODE      0     // 0 = warm white, 1 = RGB
#define MAX_BRIGHTNESS        255
#define WARM_WHITE_R          255
#define WARM_WHITE_G          180
#define WARM_WHITE_B          100

// ── OLED pages ───────────────────────────────────────────────
#define OLED_PAGE_COUNT  5
#define PAGE_LAYOUT      0
#define PAGE_CUSTOM      1
#define PAGE_LED         2
#define PAGE_WPM         3
#define PAGE_HOST        4

#endif // CONFIG_H

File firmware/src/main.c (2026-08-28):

#include "config.h"
#include "matrix.h"
#include "usb_descriptors.h"
#include "oled.h"
#include "leds.h"
#include "encoder.h"
#include "pico/stdlib.h"
#include "hardware/adc.h"
#include "hardware/timer.h"
#include <stdio.h>
#include <string.h>

int main(void) {
    stdio_init_all();
    usb_init();
    matrix_init();
    oled_init();
    leds_init();
    encoder_init();

    adc_init();
    adc_set_temp_sensor_enabled(true);

    // Startup animation
    leds_startup_wave();

    // Tracking time
    uint32_t last_scan_us = 0;
    uint32_t last_temp_ms = 0;

    // Encoder button state
    bool enc_btn_prev = false;
    uint32_t enc_btn_press_ms = 0;
    bool enc_btn_held = false;

    // Previous state for change detection
    hid_report_t prev_report = {0};
    bool first_report = true;

    while (1) {
        usb_task();

        // Parse incoming serial data from host
        int c;
        static char serial_buf[64];
        static uint8_t serial_idx = 0;
        while ((c = getchar_timeout_us(0)) != PICO_ERROR_TIMEOUT) {
            if (c == '\n' || c == '\r') {
                serial_buf[serial_idx] = '\0';
                if (serial_idx > 0 && serial_buf[0] == 'T') {
                    // Format: T:<cpu_avg>:<gpu_avg>
                    float cpu, gpu;
                    if (sscanf(serial_buf, "T:%f:%f", &cpu, &gpu) == 2) {
                        oled_set_host_temps(cpu, gpu);
                    }
                }
                serial_idx = 0;
            } else if (serial_idx < sizeof(serial_buf) - 1) {
                serial_buf[serial_idx++] = (char)c;
            }
        }

        uint32_t now_us = time_us_32();
        uint32_t now_ms = now_us / 1000;

        // Matrix scan every 1ms
        if (now_us - last_scan_us >= SCAN_INTERVAL_US) {
            last_scan_us = now_us;
            matrix_scan();

            // Check for changes
            if (matrix_changed() || first_report) {
                hid_report_t report = matrix_get_report();

                // Send change on event
                if (report.modifiers != prev_report.modifiers ||
                    memcmp(report.keys, prev_report.keys, 6) != 0 ||
                    first_report) {
                    usb_hid_send_keyboard(report.modifiers, report.keys);
                    prev_report = report;
                    first_report = false;
                }
            }
        }

        // Encoder polling
        encoder_poll();
        int8_t enc_delta = encoder_get_delta();

        // Encoder button: read from matrix (Row 5, Col 13)
        bool enc_btn_now = matrix_key_pressed(5, 13);

        if (enc_btn_now && !enc_btn_prev) {
            // Button pressed
            enc_btn_press_ms = now_ms;
            enc_btn_held = false;
        } else if (enc_btn_now && !enc_btn_held) {
            // Button held - check for long press (3s)
            if (now_ms - enc_btn_press_ms >= 3000) {
                enc_btn_held = true;
                // Toggle encoder mode: 0=volume, 1=brightness
                uint8_t mode = encoder_get_mode();
                encoder_set_mode(mode ? 0 : 1);
            }
        } else if (!enc_btn_now && enc_btn_prev) {
            // Button released - short press = play/pause
            if (!enc_btn_held) {
                usb_hid_send_consumer(0x00CD); // Play/Pause
                sleep_ms(10);
                usb_hid_send_consumer(0x0000); // Release
            }
        }
        enc_btn_prev = enc_btn_now;

        // Encoder rotation
        if (enc_delta != 0) {
            if (encoder_get_mode() == 0) {
                // Volume mode
                if (enc_delta > 0) {
                    usb_hid_send_consumer(0x00E9); // Volume Up
                } else {
                    usb_hid_send_consumer(0x00EA); // Volume Down
                }
                sleep_ms(10);
                usb_hid_send_consumer(0x0000); // Release
            } else {
                // Brightness mode
                uint8_t bright = leds_get_brightness();
                int16_t new_bright = (int16_t)bright + (enc_delta * 16);
                if (new_bright < 0) new_bright = 0;
                if (new_bright > 255) new_bright = 255;
                leds_set_brightness((uint8_t)new_bright);
            }
        }

        leds_task(now_ms);
        oled_task(now_ms);

        // Update information
        if (now_ms - last_temp_ms >= 1000) {
            last_temp_ms = now_ms;
            adc_select_input(4);
            uint16_t raw = adc_read();
            float voltage = raw * 3.3f / 4095.0f;
            float pico_temp = 27.0f - (voltage - 0.706f) / 0.001721f;
            oled_set_internal_temp(pico_temp);
            oled_set_wpm(matrix_get_wpm());
            oled_set_led_info(leds_get_mode(), leds_get_brightness());
        }
    }

    return 0;
}

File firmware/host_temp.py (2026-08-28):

#!/usr/bin/env python3
"""
Host-side temperature reader for qbMX keyboard, Using osx-cpu-temp to read Mac CPU/GPU temps and sends to Pico over USB serial.
Falls back to RP2040 internal temp if osx-cpu-temp unavailable.

Usage:
    python3 host_temp.py                    # Auto-detect serial port
    python3 host_temp.py /dev/tty.usbmodem* # Specify port
    python3 host_temp.py --test             # Test mode (no Pico needed)
"""

import sys
import time
import subprocess
import re
import argparse

def read_osx_cpu_temp():
    """Read CPU/GPU temps using osx-cpu-temp. Returns (cpu, gpu) in Celsius."""
    cpu = None
    gpu = None

    try:
        result = subprocess.run(
            ['osx-cpu-temp', '-c'],
            capture_output=True, text=True, timeout=5
        )
        # Parse "CPU: 65.0°C" or just "65.0°C"
        match = re.search(r'([\d.]+)\s*°?C', result.stdout)
        if match:
            val = float(match.group(1))
            if val > 0:
                cpu = val
    except (FileNotFoundError, subprocess.TimeoutExpired):
        pass

    try:
        result = subprocess.run(
            ['osx-cpu-temp', '-g'],
            capture_output=True, text=True, timeout=5
        )
        match = re.search(r'([\d.]+)\s*°?C', result.stdout)
        if match:
            val = float(match.group(1))
            if val > 0:
                gpu = val
    except (FileNotFoundError, subprocess.TimeoutExpired):
        pass

    return cpu, gpu


def find_pico_port():
    """Auto-detect the Pico's USB serial port."""
    import glob
    # Look for Pico CDC serial ports
    patterns = [
        '/dev/tty.usbmodem*',
        '/dev/tty.usbserial*',
    ]
    for pattern in patterns:
        ports = glob.glob(pattern)
        if ports:
            return ports[0]
    return None


def main():
    parser = argparse.ArgumentParser(description='Send Mac temps to qbMX keyboard')
    parser.add_argument('port', nargs='?', help='Serial port (auto-detect if omitted)')
    parser.add_argument('--test', action='store_true', help='Test mode, no Pico needed')
    parser.add_argument('--interval', type=float, default=2.0, help='Update interval in seconds')
    args = parser.parse_args()

    # Find port
    port_path = args.port or find_pico_port()
    if not port_path and not args.test:
        print("No Pico found. Use --test to preview output.")
        sys.exit(1)

    print(f"Port: {port_path or 'TEST MODE'}")
    print(f"Interval: {args.interval}s")
    print("Reading Mac CPU/GPU temperatures...")
    print("Press Ctrl+C to stop.\n")

    ser = None
    if not args.test:
        try:
            import serial
            ser = serial.Serial(port_path, 115200, timeout=1)
        except ImportError:
            print("pyserial not installed. Run: pip3 install pyserial")
            sys.exit(1)
        except Exception as e:
            print(f"Could not open {port_path}: {e}")
            print("Make sure the Pico is connected and not in BOOTSEL mode.")
            sys.exit(1)

    try:
        while True:
            cpu, gpu = read_osx_cpu_temp()

            # Calculate average
            temps = [t for t in [cpu, gpu] if t is not None]
            avg = sum(temps) / len(temps) if temps else None

            # Format message: "T:<cpu>:<gpu>:<avg>\n"
            # Use -1.0 for unavailable values
            cpu_val = cpu if cpu is not None else -1.0
            gpu_val = gpu if gpu is not None else -1.0
            avg_val = avg if avg is not None else -1.0

            msg = f"T:{cpu_val:.1f}:{gpu_val:.1f}:{avg_val:.1f}\n"

            if args.test:
                print(f"[TEST] {msg.strip()}")
            else:
                ser.write(msg.encode())
                ser.flush()
                cpu_str = f"{cpu:.1f}" if cpu else "N/A"
                gpu_str = f"{gpu:.1f}" if gpu else "N/A"
                avg_str = f"{avg:.1f}" if avg else "N/A"
                print(f"Sent: CPU={cpu_str} GPU={gpu_str} AVG={avg_str}")

            time.sleep(args.interval)

    except KeyboardInterrupt:
        print("\nStopped.")
    finally:
        if ser:
            ser.close()


if __name__ == '__main__':
    main()

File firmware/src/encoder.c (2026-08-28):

#include "encoder.h"
#include "config.h"
#include "hardware/gpio.h"

static volatile int8_t encoder_delta = 0;
static volatile uint8_t encoder_state = 0;
static volatile bool button_state = false;
static uint8_t encoder_mode = 0; // 0 = volume, 1 = brightness

static void gpio_callback(uint gpio, uint32_t events) {
    if (gpio == ENC_A || gpio == ENC_B) {
        uint8_t a = gpio_get(ENC_A);
        uint8_t b = gpio_get(ENC_B);
        uint8_t new_state = (a << 1) | b;

        // Quadrature decoding
        switch (encoder_state) {
            case 0b00:
                if (new_state == 0b01) encoder_delta++;
                else if (new_state == 0b10) encoder_delta--;
                break;
            case 0b01:
                if (new_state == 0b11) encoder_delta++;
                else if (new_state == 0b00) encoder_delta--;
                break;
            case 0b11:
                if (new_state == 0b10) encoder_delta++;
                else if (new_state == 0b01) encoder_delta--;
                break;
            case 0b10:
                if (new_state == 0b00) encoder_delta++;
                else if (new_state == 0b11) encoder_delta--;
                break;
        }
        encoder_state = new_state;
    }
}

void encoder_init(void) {
    gpio_init(ENC_A);
    gpio_set_dir(ENC_A, GPIO_IN);
    gpio_pull_up(ENC_A);

    gpio_init(ENC_B);
    gpio_set_dir(ENC_B, GPIO_IN);
    gpio_pull_up(ENC_B);

    encoder_state = (gpio_get(ENC_A) << 1) | gpio_get(ENC_B);

    gpio_set_irq_enabled(ENC_A, GPIO_IRQ_EDGE_RISE | GPIO_IRQ_EDGE_FALL, true);
    gpio_set_irq_enabled(ENC_B, GPIO_IRQ_EDGE_RISE | GPIO_IRQ_EDGE_FALL, true);
    gpio_add_raw_irq_handler(0, gpio_callback);
    irq_set_enabled(IO_IRQ_BANK0, true);
}

void encoder_poll(void) {
}

int8_t encoder_get_delta(void) {
    int32_t val = __atomic_exchange_n(&encoder_delta, 0, __ATOMIC_SEQ_CST);
    if (val > 3) val = 3;
    if (val < -3) val = -3;
    return (int8_t)val;
}

bool encoder_button_pressed(void) {
    return button_state;
}

void encoder_set_mode(uint8_t mode) {
    encoder_mode = mode;
}

uint8_t encoder_get_mode(void) {
    return encoder_mode;
}

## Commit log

2026-08-21 init commit
    [128x32-OLED.STEP, DSA 1.25u.step, DSA 1.5u.step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]
2026-08-21 Untrack key-switches.pretty submodule and ignore it
2026-08-24 csv init
    [keeb.kicad_sch, pcb.csv]
2026-08-24 finalised production render and casing
    [case.step, keeb.kicad_sch, plate.kicad_pcb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]
2026-08-25 plate pcb + final csv
    [pcb.csv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]
2026-08-25 renamed pcb.csv to bom.csv
    [bom.csv]
2026-08-26 add single panel variant (kicad project, gerbers, layout json)
    [single_panel-B_Adhesive.gbr, single_panel-B_Courtyard.gbr, single_panel-B_Cu.gbr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]
2026-08-28 Add firmware with host temp, encoder modes, and F13-F18 keys
    - Firmware: bare-metal Pico SDK for RP2040, 6x15 matrix, SSD1306 OLED, SK6812 LEDs
    - Host temp: Python script sends Mac CPU/GPU temps via USB serial to OLED
    - Encoder: short press = play/pause, long press (3s) = toggle volume/brightness mode
    - 6 programmable keys mapped to F13-F18 (HID 0x68-0x6D)
    - OLED page shows CPU avg, GPU avg, and Pico internal temp
    - Updated README with correct OLED page list
    - Added journal entry for host temperature integration
    [config.h, encoder.c, host_temp.py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]
2026-08-29 modified models, added more pictures to journal
    [base.step, bom.csv, case.step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]
2026-09-06 update price
    [bom.csv]
2026-10-08 Reformat build journal to JOURNAL.md for Forge sync
    Restructured the 6 build-log sections into dated # entries with
    YAML frontmatter and per-entry Total time spent, required by Forge.
    Prose, hours and images are unchanged; dates were reconstructed
    from git history and file timestamps.
    - Rename Journal.md -> JOURNAL.md (case-only, via git mv)
    - Add firmware screenshot to the Firmware entry
    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
